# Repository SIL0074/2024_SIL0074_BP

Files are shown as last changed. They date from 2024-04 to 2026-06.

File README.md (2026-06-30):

# Přehrávač internetového rádia využívající technologii WiFi 🇨🇿 🇸🇰

Tento repozitář obsahuje zdrojové kódy k bakalářské práci, která se zabývá návrhem a konstrukcí zařízení pro přehrávání internetových rádií pomocí modulu ESP32 s integrovanou WiFi technologií.

Práce zahrnuje teoretickou část, která se věnuje stručně WiFi a Bluetooth, mikrokontroléru ESP32, zvukovému modulu VS1053B, LCD displeji, IR ovladači a pulznímu enkodéru. Důkladně popisuje rozložení pinů těchto modulů, jejich funkce a možné využití. Dále obsahuje rešerši komerčních WiFi rádií. Cílem práce je nejen navrhnout a sestrojit funkční zařízení, ale také detailně prozkoumat technické aspekty WiFi rádií a uživatelského rozhraní. Tento projekt má potenciál přispět k rozvoji oblasti internetových rádií a sloužit jako inspirace pro další inovace v této oblasti.

## Použitý hardware

- Mikrokontrolér ESP32 (Wi-Fi / Bluetooth SoC)
- Zvukový dekódovací modul VS1053B, LCD displej
- Infračervený (IR) ovladač a přijímač, rotační pulzní enkodér

## Autor

Bc. Pavel Šiller (2024)

**Usnesení:** Tento projekt byl vytvořen primárně pro účely vysokoškolské bakalářské práce. Zdrojové kódy a hardwarové návrhy jsou poskytovány „tak jak jsou“ bez záruky vhodnosti pro produkční využití nebo průmyslové nasazení. Autor nenese odpovědnost za případné škody způsobené jejich použitím. Uvedená řešení mohou sloužit jako vzdělávací demonstrace a inspirace pro vývoj IoT a audio systémů.

---

# Internet Radio Player Using WiFi Technology 🇬🇧 🇺🇸

This repository contains the source code for a bachelor’s thesis focused on the design and construction of a device for playing internet radios using the ESP32 module with integrated WiFi technology.

The work includes a theoretical part that addresses WiFi and Bluetooth technology, the ESP32 microcontroller, the VS1053B audio module, an LCD display, an IR controller, and a rotary encoder. It thoroughly describes the pinout of these modules, their functions, and potential applications. Furthermore, it includes a review of commercial WiFi radios. The aim of the thesis is not only to design and build a functional device but also to extensively explore the technical aspects of WiFi radios, and user interface. This project has the potential to contribute to the development of internet radios and serve as inspiration for further innovations in this field.

## Used hardware

- ESP32 Microcontroller (Wi-Fi / Bluetooth SoC)
- VS1053B Audio Decoder Module, LCD Display Module
- Infrared (IR) remote controller & receiver, rotary pulse encoder

## Author

Bc. Pavel Siller (2024)

**Disclaimer:** This project was created primarily for the purposes of a university bachelor’s thesis. Source codes and hardware designs are provided "as is" without warranty of fitness for production use or industrial deployment. The author takes no responsibility for any damages caused by their use. The provided solutions serve as educational demonstrations and inspiration for developing IoT and audio systems.

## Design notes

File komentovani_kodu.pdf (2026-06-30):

## Komentované cásti kódu ˇ

//Načtení všech potřebných knihoven

#include <WiFi.h>

#include <ESPAsyncWebServer.h>

#include <ArduinoOTA.h>

#include <HTTPClient.h>

#include <cbuf.h>

#include <SPI.h>

#include <Arduino.h>

#include <Preferences.h>

#include <web_content.h>

#include <LiquidCrystal_I2C.h>

#include <IRremoteESP8266.h>

#include <IRrecv.h>

#include <BluetoothA2DPSink.h>

#include <Adafruit_VS1053.h>

#include <VS1053.h>

#include <RotaryEncoder.h>

Prvne je pot ˇ | ˇreba nacíst veškeré knihovny pot ˇ | ˇrebné pro funkci rádia. Pˇridány jsou
knihovny Wifi.h, HTTPClient.h pro správnou funkci spojení se streamovacím serverem. Pro funkci vytvoˇrení webového serveru pˇrímo v ESP jsem použil knihovny ESPAsyncWeb-Server.h a mnou vytvoˇrenou knihovnu web_content.h pro definování struktury HTML kódu. Dále jsou zde knihovny jako ArduinoOTA.h pro funkci OTA nebo Preferences.h pro možnost ukládání promenných natrvalo do NVS (Non-Volatile Storage), která je náhražkou ˇ pameti EEPROM (Electric Erasable Programable Read Only Memory) u Arduina. ˇ Knihovny používané pro Bluetooth, jako jsou BluetoothA2DPSink.h a cbuf.h. Knihovny SPI.h, VS1053.h a Adafruit_VS1053.h pro zvukovou kartu a knihovny pro periferie a ovládací prvky IRemoteESP8266.h, IRrecv.h, RotaryEncoder.h a LiquidCrystal_I2C.

//Definování pinů

//Zvuková karta VS1053b

#define VS1053_CS 5

#define VS1053_DCS 16

#define VS1053_DREQ 4

#define VS1053_CSSD 17

#define CLK 18

#define MISO 19

#define MOSI 23

//Infračervený přijímač (OUT)

#define IR_REC 2

//Tlačítko pro přepínání mezi WiFi a Bluetooth režimy

#define BT_PIN 33

//Rotační enkódér

#define BUTTON_PIN 12

#define DT_PIN 13

#define CLK_PIN 14

//Název zařízení v Bluetooth režimu

#define BT_NAME "ESP32 RADIO"

//Velikost bufferu (vyrovnávací paměti) pro knihovnu Adafruit_VS1053.h

- režim Bluetooth

#define BUFFSIZE 32

Další úryvek kódu definuje pˇriˇrazení pin˚u jednotlivým promenným. ˇ
V pˇríloze práce v souboru main.cpp je vyzobrazena inicializace knihoven i vytvoˇrení
potˇrebných promenných na ˇ | ˇrádcích 48 - 194.

//Funkce pro spouštění serveru v případě, že se ESP32 nedokázalo př

ipojit k žádné WiFi
void serverRun() {

WiFi.softAP(server_ssid, server_heslo);

server.on("/", HTTP_GET, [](AsyncWebServerRequest *request){

request->send(200, "text/html", obsahWeb); //Vytvoří se server

na IP zobrazené na displeji, kde se zobrazí html kód z prom

ěnné obsahWeb, která je uložená ve flash spolu s programem });

server.on("/", HTTP_POST, [](AsyncWebServerRequest *request){

if(request->hasParam("ssid", true) && request->hasParam("

password", true)) {

AsyncWebParameter* ssidParam = request->getParam("ssid",

true);

AsyncWebParameter* passwordParam = request->getParam("

password", true);

String newSSID = ssidParam->value();

String newPassword = passwordParam->value();

//Ukládání zadaného SSID a hesla do sharedPrefs

inicializované při spuštění ESP preferences.begin("wifi", false);

preferences.putString("ssid", newSSID);

preferences.putString("password", newPassword);

preferences.end();

delay(1000);

ESP.restart();

} else {

request->send(400, "text/plain", "Chybí potřebné parametry" );
}
});

server.begin();

//Serial.println("Server běží!");
}

Funkce pro vytvoˇrení webového serveru na ESP32. Webový serveru bude mít strukturu souboru web_content.h, kterou si m˚užete zobrazit v pˇríloze práce.

if (server_vych_mod == RADIO){

serverRun();

Serial.println("Přepínám na režim SERVER");

server_vych_mod = SERVER;
}

else {

serverRun();
}
}

else if (WiFi.isConnected()){

Serial.println("Spojení s WiFi úspěšně navázáno");
}
Spouští se pˇri neúspešném p ˇ | ˇripojení pomocí zadaných parametr˚u SSID a hesla k WiFi. Pˇri
tomto je tˇreba se pˇripojit na ESP32 pomocí WiFi a zadat do webového prohlížece IP adresu ˇ zobrazenou na LCD. Poté potvrdit odeslání nového SSID a hesla.

//Funkce volána při přepnutí z WiFi režimu do Bluetooth režimu

void startBluetooth(){

Serial.println("Přepínám na BT režim");

if (rad_vych_mod != BT_REZIM){

lcd.clear();

lcd.setCursor(0, 0);

lcd.print("BLUETOOTH");

lcd.setCursor(0,1);

lcd.print("Nastavovani..."); //Vypsání BLUETOOTH na displej }

stream_prehravac.stopSong(); //Pozastavení inicializované knihovny

VS1053.h
stream_prehravac.softReset();

delay(1000);

if (!bt_prehravac.begin()) {

Serial.println(F("Chyba VS1053b, zkontroluj zapojení pinů!"));

lcd.clear();

lcd.setCursor(0,0);

lcd.print("Chyba E1");

while(1);

}

bt_prehravac.begin(); //Start zvukové karty pomocí knihovny

Adafruit_VS1053.h

ArduinoOTA.end(); //Vypnutí OTA

WiFi.mode(WIFI_OFF); //Vypnutí WiFi

WiFi.disconnect();

Serial.println("WiFi režim: " + WiFi.getMode()); //Testovací výpis

pro kontrolu
delay(1000);

circBuffer.flush(); //Vyprázdnění vyrovnávací paměti

Serial.println(stream_prehravac.isChipConnected()); //Testovací vý

pis pro kontrolu
a2dp_sink.set_stream_reader(dat_stream, false); //Nastavení

Bluetooth streamu
a2dp_sink.set_avrc_metadata_callback(metadata); //Nastavení metadat
- nepoužívám jej pro výpis jinde, než v konzoli, není třeba a2dp_sink.start(BT_NAME); //Start Bluetooth se jménem v BT_NAME

Serial.println(a2dp_sink.get_connected_source_name()); //Testovací v

ýpis pro kontrolu
delay(1000);

circBuffer.write((char *)bt_wav_header, 44);

delay(1000);

Serial.println("Bluetooth režim"); //Testovací výpis pro kontrolu

if (rad_vych_mod != BT_REZIM){ //Výpis informace o režimu na LCD

displej spolu s názvem BT
lcd.clear();

lcd.setCursor(0, 0);

lcd.print("BLUETOOTH");

lcd.setCursor(0,1);

lcd.print(BT_NAME);
}

rad_vych_mod = BT_REZIM; //Přepnutí režimu na BT_REZIM }

Pomocí funkce výše se pak zapíná Bluetooth režim (respektive se vypíná WiFi a zapíná Bluetooth), kdy je tˇreba vypnout WiFi z d˚uvodu interference ve stejném kmitoctovém pásmu. ˇ Poté je tˇreba vypnout inicializovanou zvukovou kartu knihovny VS1053.h a inicializovat zvukovou kartu knihovny Adafruit_VS1053.h.

//Tato funkce je volána při přepínání z Bluetooth do rádiového režimu

void stopBluetooth(){

lcd.clear(); //Výpis toho, co se s rádiem děje

lcd.setCursor(0, 0);

lcd.print("BLUETOOTH");

lcd.setCursor(0,1);

lcd.print("Vypinani...");

a2dp_sink.end();

delay(500);

Serial.println("Přepínám na WiFi režim");

bt_prehravac.stopPlaying();

bt_prehravac.reset();

ESP.restart();

Funkce pro vypnutí Bluetooth a pˇrepnutí do WiFi režimu. Kv˚uli nemožnosti správneˇ vypnout WiFi v ESP jsem nucen restartovat rádio a pˇrepojit do WiFi režimu až po startu.

void Enkoder() {

static int poz = 1;
int novaPoz = enkoder->getPosition(); //Získání pozice

int smerST;

V této funkci enkóderu se nachází zvlášt’ switch pro pˇrepínání režim˚u WiFi/Bluetooth a v
každém z nich poté ješte switch mezi p ˇ | ˇrepínámím hlasitost/stanice.

case WIFI_REZIM:
if (poz != novaPoz) {

switch (enk_vych_mod) { //Volba režimu enkódéru

case enkoder_stanice: //Přepínání stanic

//Zjištění směru otáčení

smerST = (int)(enkoder->getDirection());

//Podmínky pro otáčení enkódérem

if (smerST > 0 && ID_stanice < pocet_stanic) {

ID_stanice++;
} else if (smerST < 0 && ID_stanice > 1) {

ID_stanice--;
}

Serial.print("pozST:"); //Vypisování do serialu (pro testování)

Serial.print(ID_stanice);

Serial.print("smerST:");

Serial.println(smerST);

poz = novaPoz; //Uložení pozice do poz

zaloha_stanice = ID_stanice; //Uložení ID stanice do

zaloha_stanice

break;
case enkoder_hlasitost: //Změna hlasitosti

int smerVO = (int)(enkoder->getDirection()); //smerVO nabývá

hodnot 1 a -1 dle knihovny RotaryEncoder.h
if (smerVO > 0 && Volume < 100) {//Pokud je 1, zvýšení

hlasitosti o 1

Volume++;
} else if (smerVO < 0 && Volume > 29) {//Pokud je -1, snížení

hlasitosti o 1

Volume--;
}

Serial.print("pozVO: ");//Vypisování do serialu (pro testování)

Serial.print(enkoderPozVO);

Serial.print("smerVO: ");

Serial.println(smerVO);

Serial.print("Volume: ");

Serial.print(Volume);

poz = novaPoz;//Zápis nové polohy

break;
}
}

break;

Zde je zase videt, jakým zp˚usobem se chovají p ˇ | ˇrepnuté case ve WiFi režimu. Vše je na
základe sm ˇ | eru otá ˇ | cení enkóderu. Samoz ˇ | ˇrejme nechybí ošet ˇ | ˇrení hranicních interval˚u hlasitosti. ˇ

case BT_REZIM:

if (poz != novaPoz) {

switch (enk_vych_mod) {

case enkoder_stanice: //Využil jsem již existující

enkoder_stanice (přepíná skladby v playlistu připojeného zaří

zení)

//Zjištění směru otáčení smerST = (int)(enkoder->getDirection());

if (smerST > 0) {

a2dp_sink.next(); //Přepnutí vpřed

} else if (smerST < 0) {

a2dp_sink.previous();//Přepnutí vzad
}

Serial.print("posST:");//Vypisování do serialu (pro testování)

Serial.print(" dirST:");

Serial.println(smerST);

Serial.print(bluetooth_media_title);

poz = novaPoz;//Zápis nové polohy

break;

case enkoder_hlasitost://Jako u WiFi režimu je zde změna

hlasitosti
//Zjištění směru otáčení

int smerVO = (int)(enkoder->getDirection());

//Podmínky pro otáčení enkódérem

if (smerVO > 0 && VolumeBT > 1) {

VolumeBT--;
} else if (smerVO < 0 && VolumeBT < 101) {

VolumeBT++;
}

Serial.print("posVO:");//Vypisování do serialu (pro testování)

Serial.print(enkoderPozVO);

Serial.print(" dirVO:");

Serial.println(smerVO);

Serial.print(" VolumeBT:");

Serial.print(VolumeBT);

poz = novaPoz;//Zápis nové polohy

break;
}
}

break;
}

Opet p ˇ ˇrepínání hlasitost/stanice v Bluetooth režimu.

//Funkce pro tlačítko, které přepíná režimy enkódéru

void handleButton() {

if (digitalRead(BUTTON_PIN) == LOW) {

if (!buttonPressed) {

buttonPressed = true;

//přepnutí stavu

if (enk_vych_mod == enkoder_stanice) {

enk_vych_mod = enkoder_hlasitost; Serial.println("Měním hlasitost!");

} else {

enk_vych_mod = enkoder_stanice; Serial.println("Přepínám stanice!"); }
}

} else {

buttonPressed = false;
}
}
Funkce sloužící pro podchycení funkcnosti tla ˇ | cítka na enkóderu. ˇ
Mení stavy p ˇ | ˇrepnutí hlasitost/stanice v promenné ˇ | enk_vych_mod.

void IROvladac() {

if (irrecv.decode(&decod_prij)) {

Serial.println(decod_prij.value, HEX);

V tomto úryvku nalezneme funkci IR diody. Pˇríchozí signál je tˇreba dekódovat a následneˇ na základe p ˇ ˇrijatého hexadecimálního kódu (HEX) urcit proces, který se má vykonat. ˇ switch (rad_vych_mod){ //Pro WiFi a Bluetooth rozlišné funkce

case WIFI_REZIM:

if (decod_prij.value == 0xFFB04F) { // tlačítko "#"

Serial.println("Restart za 2s!");

delay(1500);

ESP.restart();
}

Jak jsem zmínil výše, je tˇreba pˇriˇradit hexadecimálnímu kódu jeho úlohu. Zde je pˇríklad
HEX kódu 0xFFB04F pˇriˇrazeno pro restart ESP (jedná se o tlacítko se symbolem ˇ | #). Tyto
stejné úlohy lze pˇriˇrazovat v Bluetooth režimu zvlášt’.

String Scroll_displeje(String LCD_text){

String LCD_hot;

String LCD_proces = odsazeni + LCD_text + odsazeni; LCD_hot = LCD_proces.substring(x1,x2);

x1++;

x2++;
if (x1>LCD_proces.length()){

x1=16;

x2=0;
}

return LCD_hot;
}

Zde vidíme funkci pro možnost pohyblivého displeje (respektive jeho prvního ˇrádku) z d˚uvodu délky názvu stanic, zeme p˚uvodu stanice a identifikátoru stanice. Kód je inspirován ˇ kódem ze stránky s názvem I2C LCD interfacing with Arduino Display Scrolling Text and Custom Characters. (https://microcontrollerslab.com/i2c-lcd-arduino-tutorial/) [?]

//Funkce pro tlačítko, které přepíná mezi režimy WiFi a BT

void BTbutton() {

//Ošetření nechtěného přepínání

BTbuttonState = digitalRead(BT_PIN);

unsigned long currentTime = millis();

if (BTbuttonState == LOW) {

if (currentTime - BTlastButtonPressTime >= BTdebounceDelay) {

delay(50);

if (rad_vych_mod == WIFI_REZIM) {

//Zapnutí Bluetooth, pokud jsme ve WiFi režimu

startBluetooth();

Serial.println("Přepínám do BT režimu");

delay(1000);

Serial.println("Přepnuto!");

} else if (rad_vych_mod == BT_REZIM) {

//Zastavení Bluetooth, pokud jsme v Bluetooth režimu

stopBluetooth();

Serial.println("Přepínám do WiFi režimu");

delay(1000);

Serial.println("Přepnuto!");
}

BTlastButtonPressTime = currentTime; }
}
}
Tlacítko pro p ˇ | ˇrepínání režim˚u WiFi/Bluetooth. Je zde nastavena ochrana proti nechtenému ˇ
delšímu držení tlacítka. ˇ

//Funkce pro samotný stream

void stream(){

if(!webclient.connected() || pamet_ID_stanice!=ID_stanice){

if(webclient.connect(host, 80)){ | //Př

ipojení se k požadovanému streamu webclient.print(String("GET ") + cesta+ " HTTP/1.1\r\n" + "Host:

" + host + "\r\n" + "Connection: close\r\n\r\n");

pamet_ID_stanice=ID_stanice;
Serial.println(nazev); //Vypsání názvu do serialu, pro testovací

účely
lcd.clear(); //čistka displeje
}

else {

Serial.println("Nepodařilo se připojit k serveru.");

lcd.clear();

lcd.setCursor(0,0);

lcd.println("Chyba E2");

stream_prehravac.stopSong(); }
}

if(webclient.available() > 0){

uint8_t bytesread = webclient.read(mp3buff,32); | //naplnění

bufferu při dostupnosti serveru
stream_prehravac.playChunk(mp3buff,bytesread); | //přehrávání

audio streamu z bufferu na výstup VS1053
}
}
Zde je proces samotného žádání streamu po streamovacím serveru. V pˇrípade úsp ˇ | ešného ˇ
pˇripojení se naplní vyrovnávací pamet’ (buffer) a p ˇ | ˇrehraje audio obsah.

//Naplnění bufferu

void dat_stream(const uint8_t *data, uint32_t length) {

if (circBuffer.room() > length) {

if (length > 0) {

circBuffer.write((char *)data, length); }

} else {
Serial.println("\nŽádná streamovací data!"); }
}
Naplnení dat do ˇ | circBuffer.

//Průběh Bluetooth streamu, volá se ve smyčce

void handle_stream() {

if (circBuffer.available()) {

if (bt_prehravac.readyForData()) { //Dotaz na zvukovou kartu, zda

může přijímat další data

int bytesRead = circBuffer.read((char *)mp3buff, BUFFSIZE);

//Zachycení chybného čtení dat

if (bytesRead != BUFFSIZE) Serial.printf("Málo dat v bufferu,

kvalita audia může být ovlivněna", bytesRead);

bt_prehravac.playData(mp3buff, bytesRead); //Zaslání dat do

zvukové karty
}
}
}
Hlavní funkce pro beh bluetooth spojení. Data z ˇ | circBuffer se pouští na zvukové desce.

void setup ()
{

Serial.begin(115200);

delay(500);

SPI.begin(); //Inicializace SPI

if (!bt_prehravac.begin()) {

Serial.println(F("Nedetekováno žádné VS1053B, zkontroluj zapojení

pinů! Zařízení nebude fungovat!"));

while(1);
}

stream_prehravac.begin(); // Start zvukové karty VS1053B pomocí

knihovny VS1053.h

pinMode(BUTTON_PIN, INPUT_PULLUP); //Nastavení GPIO pinů jako vstup (

tlačítko na enkódéru a Bluetooth tlačítko)

pinMode(BT_PIN, INPUT_PULLUP);

Serial.println("Enkódér úspěšně inicializován!");

enkoder = new RotaryEncoder(DT_PIN, CLK_PIN, RotaryEncoder::LatchMode

::TWO03);//Inicializace rotačního enkódéru

irrecv.enableIRIn(); //Inicializace IR diody

attachInterrupt(digitalPinToInterrupt(DT_PIN), getPoz, CHANGE); //

Nastavení přerušení při změně na DT_PIN nebo CLK_PIN attachInterrupt(digitalPinToInterrupt(CLK_PIN), getPoz, CHANGE);

lcd.init(); // Inicializace LCD displeje

lcd.backlight();

lcd.clear();

lcd.setCursor(0,0);

lcd.print("Radio - SIL0074");

lcd.setCursor(0,1);

lcd.print("Start radia");

Serial.println("Startuji");

WiFi.mode(WIFI_STA); //Nastavení režimu WiFi (STA - station mode)

delay(1000);

// WiFi.begin(ssid, pass);

//serverRun();

WiFi.begin(ssid, pass); //Připojení pomocí SSID a hesla

Úryvek kódu je z funkce setup(), kde se provede nastavení režim˚u pin˚u, režimy enkóderu,

aktivace displeje nebo se nastaví režim WiFi na STA (Station mode). Je zde taktéž pokus o prvotní pˇripojení na WiFi s parametry SSID a heslem.

if (!WiFi.isConnected()) { //Jestliže se nepodaří ani to, informuje

se uživatele o chybě spojení na serial
Serial.println("Chyba připojení!");

//Spuštění serveru a přepnutí do režimu SERVER

if (server_vych_mod == RADIO){

serverRun();

Serial.println("Přepínám na režim SERVER");

server_vych_mod = SERVER;
}

else {

serverRun();
}
}

else if (WiFi.isConnected()){

Serial.println("Spojení s WiFi úspěšně navázáno"); }

Podmínka pro úspešné ˇ | ci neúsp ˇ | ešné p ˇ | ˇripojení.
V pˇrípade úsp ˇ | ešného spojení p ˇ | ˇrejde rádio volne setup funkcí bez zm ˇ | eny režimu. Jestliže ˇ
se však nepodaˇrí pˇripojit, spustí se server režim, ve kterém lze manuálne nastavit SSID a ˇ heslo.

//Zprovoznění OTA

ArduinoOTA.setHostname("ESP32");

//ArduinoOTA.setPassword("SIL0074"); //možnost nastavení hesla

ArduinoOTA.begin();

Spuštení OTA, je zde možnost nastavit heslo, tuto možnost jsem nevyužil. ˇ

preferences.begin("radio", true); //Získání hodnot z sharedPrefs

Volume = preferences.getInt("Volume", Volume);

VolumeBT = preferences.getInt("VolumeBT", VolumeBT);

ID_stanice = preferences.getInt("ID_stanice", ID_stanice);

preferences.end();

Nactení dat z ˇ | preferences, do kterých se ukládá aktuální hodnota hlasitosti z obou režim˚u a
identifikátor stanice. Jsou tak zachované i po restartu rádia.

//Hlavní smyčka programu

void loop()
{

switch(server_vych_mod){//Přepínání mezi RADIO a SERVER režimem

case RADIO:

Ukázka hlavní smycky, kde se pomocí switche ˇ | server_vych_mod najede do pˇríslušného
režimu radio/server.

switch(rad_vych_mod)//Přepínání mezi WiFi a Bluetooth režimem

{

case WIFI_REZIM:

V režimu radio se poté pˇrepíná mezi režimy WiFi/Bluetooth.

//V případě server režimu

case SERVER:

if (!IPdone) {

lcd.clear();

lcd.setCursor(0, 0);

lcd.print("Server rezim");//Výpis na LCD displej

lcd.setCursor(0, 1);

lcd.print("IP: ");//Výpis na LCD displej

String serverIP = WiFi.softAPIP().toString();

lcd.print(serverIP);//Výpis IP serveru na LCD displej

Serial.println("IP VYPSANA");

IPdone = true;
}

Prikazy(); //Detekce příkazů v server režimu

break;

V režimu server se už nepˇrepíná a pouze se vypíše na LCD displej potˇrebný text pro informaci uživatele.

case WIFI_REZIM:

if (Obnova >= 450){//Po kolika cyklech se má obnovit LCD

Obnova = 0; //Reset

String nazevCely = nazev + "|" + nar + "|" + ID_stanice;

lcd.setCursor(0, 0);

String pohybText = Scroll_displeje(nazevCely);

lcd.print(pohybText); //vypsání infa o stanici na první řádek LCD

Zde se celý režim odehrává pod podmínkou pocítadla ˇ Obnova, urcuje, po kolika opakováních ˇ se vykoná aktualizace hlasitosti a LCD displeje. Hodnota 450 je ideální pro plynulou obnovu a minimalizaci efektu ghosting na displeji.
Dále se zde volá funkce pro pohyblivý název stanice, zemi p˚uvodu stanice a identifikátor stanice.

if (Volume != predVolume) {

lcd.setCursor(0, 1);

lcd.print(" | "); //Smazání druhého řádku LCD

displeje
lcd.setCursor(0, 1);

if (Volume < 30){

lcd.print("Zvuk vypnut");//vypsání na druhý řádek LCD }

else{

lcd.print("Hlasitost: ");//vypsání na druhý řádek LCD

lcd.print(mapVolume);

lcd.print ("%");
}

//aktualizace hlasitosti

predVolume = Volume;
}

else{

lcd.setCursor(0, 1);

if (Volume < 30){

lcd.print("Zvuk vypnut"); //vypsání na druhý řádek LCD }

else{

lcd.print("Hlasitost: ");//vypsání na druhý řádek LCD

lcd.print(mapVolume);

lcd.print ("%");
}
}

preferences.begin("radio", false); //ukládání do prefs

preferences.putInt("Volume", Volume);

preferences.putInt("ID_stanice", ID_stanice);

preferences.end();
}
Funkcnost a aktualizace hlasitosti ve smy ˇ | cce pouze však ve chvíli, kdy se hlasitost zm ˇ | enila ˇ
(aktualizace neprobehne, jestliže je hlasitost na stejné úrovni). Uložení hodnot ˇ | | Volume a
ID_stanice do preferences.

switch(ID_stanice){ | // Přepínání stanic - ID stanice

case 1:

nazev = "Hitradio Orion";

host = "ice.abradio.cz";
cesta= "/orion128.mp3";

nar ="CZ";

break;

case 2:

nazev = "Evropa 2";

host= "ice.actve.net";
cesta= "/fm-evropa2-128";

nar ="CZ";

break;

Ukázka funkcnosti r˚uzných stanic, nachází se zde switch pro p ˇ | ˇrepínaní ID_stanice. Každá
stanice má pak vlastní case a parametry, které se nacítají a zobrazují na displej. ˇ
Já mám nastaveno 30 stanic, tudíž mám 30 case.

stream(); //funkce pro stream

IROvladac(); //aktualizace IR

Enkoder();//aktualizace enkódéru

handleButton(); //aktualizace tlačítka

Prikazy();//aktualizace příkázů

BTbutton();//aktualizace BT tlačítka

Opet volány všechny funkce zmín ˇ | ené výše. ˇ

//Funkce v BT režimu

case BT_REZIM:
//Pokud není BT spuštěno, zapni jej

if (!a2dp_sink.is_connected()){

startBluetooth();
}

//Refresh LCD v BT režimu

if (Obnova >= 20000){

Obnova=0;
bt_prehravac.setVolume(VolumeBT, VolumeBT); //Nastavení hlasitosti

VS1053b

V bluetooth režimu se vyskytuje pocítadlo ˇ | Obnova taktéž, je nastaveno na rozdílnou hodnotu,
protože je bluetooth na výkon o dost nárocnˇ ejší a p ˇ | ˇri cast ˇ | ejších obnovách mohou nastat ˇ
problémy. Taková vysoká hodnota pocítadla však nijak nezhoršuje zážitek z rádia. ˇ
Taktéž se nastavuje hlasitost na zvukovou desku (v této knihovne žáleží na levém a ˇ pravém kanálu, tudíž je tˇreba vyplnit dve pozice). ˇ

//Mapování hodnot hlasitosti v jiném pořadí a v jiném intervalu

int mapVolumeBT = map(VolumeBT, 1, 100, 100, 1);

if (mapVolumeBT == 0 || VolumeBT == 254){

lcd.clear();

lcd.setCursor(0, 0);

lcd.print("BLUETOOTH");//Výpis na LCD displej

lcd.setCursor(0,1);

lcd.print("Zvuk vypnut"); //Výpis na LCD displej
}
Úryvek kódu ukazuje mapování hodnot v opacném po ˇ | ˇradí, knihovna totiž pracuje s opac-ˇ

nými hodnotami a chceme, abychom na LCD displeji videli, že 100% je opravdu hlasitost ˇ maximální, nikoliv minimální.
Pokud je zvuk vypnut, na displej se vypíše pˇríslušný text.

preferences.begin("radio", false); // Uložení hodnot do shared prefs

preferences.putInt("VolumeBT", VolumeBT);

preferences.end();

Uložení hodnoty hlasitosti v bluetooth režimu VolumeBT do preferences.

handle_stream(); //aktualizace streamu

IROvladac(); //aktualizace IR

Enkoder();//aktualizace enkódéru

handleButton(); //aktualizace tlačítka

Prikazy();//aktualizace příkázů

BTbutton();//aktualizace BT tlačítka

Obnova++;

Volání potˇrebných funkcí a inkrementace promenné ˇ Obnova.

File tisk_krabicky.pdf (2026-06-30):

Príprava krabi ˇ | cky pro 3D tisk ˇ
Vybereme objekt levým tlacítkem myši a v pravém horním rohu klikneme na tla ˇ | cítko ˇ
„Export“.

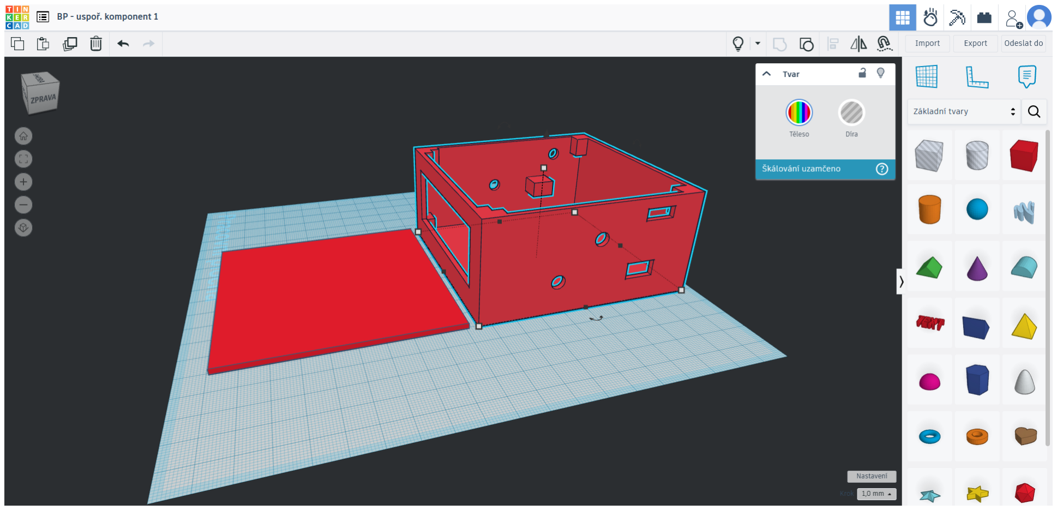
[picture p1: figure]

Obrázek 1: Export modelu z TinkerCAD prostˇredí do .stl formátu - oznacení objektu ˇ

Poté vybereme možnost „.STL“ a soubor si uložíme kdekoliv na úložišti.

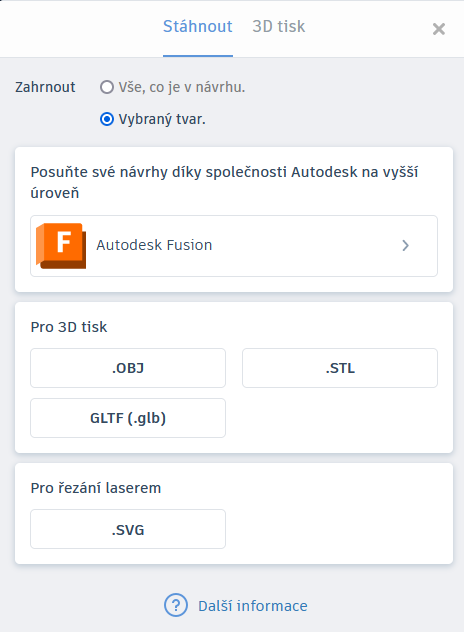
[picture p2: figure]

Obrázek 2: Export modelu z TinkerCAD prostˇredí do .stl formátu - export

Stejný postup aplikujeme pro víko, budeme mít tedy dva .stl objekty.
K dalšímu kroku potˇrebujeme program, který nám pˇripraví model k tisku a zašle model tiskárne. Pro tento krok jsem použil program PrusaSlicer. (https://www.prusa3d.com/cs/stranka/prusaslicer_424/) V tomto programu si oba mo- ˇ
dely otevˇreme. Udeláme to nap ˇ | ˇr. tak, že .stl soubor pˇretáhneme na spouštecí .exe soubor ˇ
PrusaSlicer.

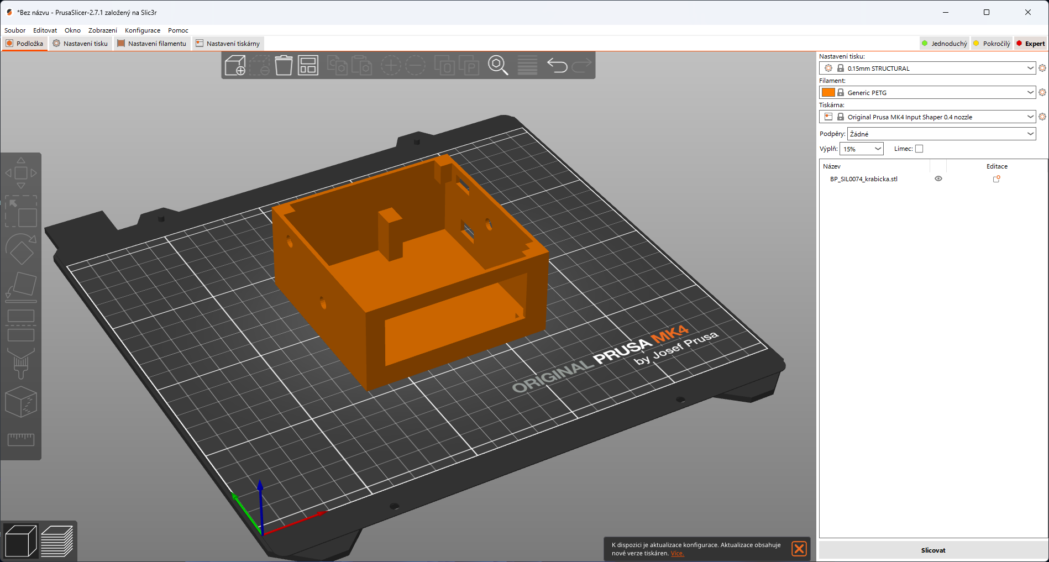
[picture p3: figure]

Obrázek 3: Otevˇrený program s importovaným modelem krabicky ˇ

Nyní musíme nastavit typy podper, pro krabi ˇ | cku se mi osv ˇ | edˇ cilo používat tzv. organické ˇ
podpery. Nastavíme je tak, že p ˇ | ˇrejdeme do sekce „Nastavení tisku“ v levém horním rohu a
poté do podsekce „Podpery“ ˇ | .

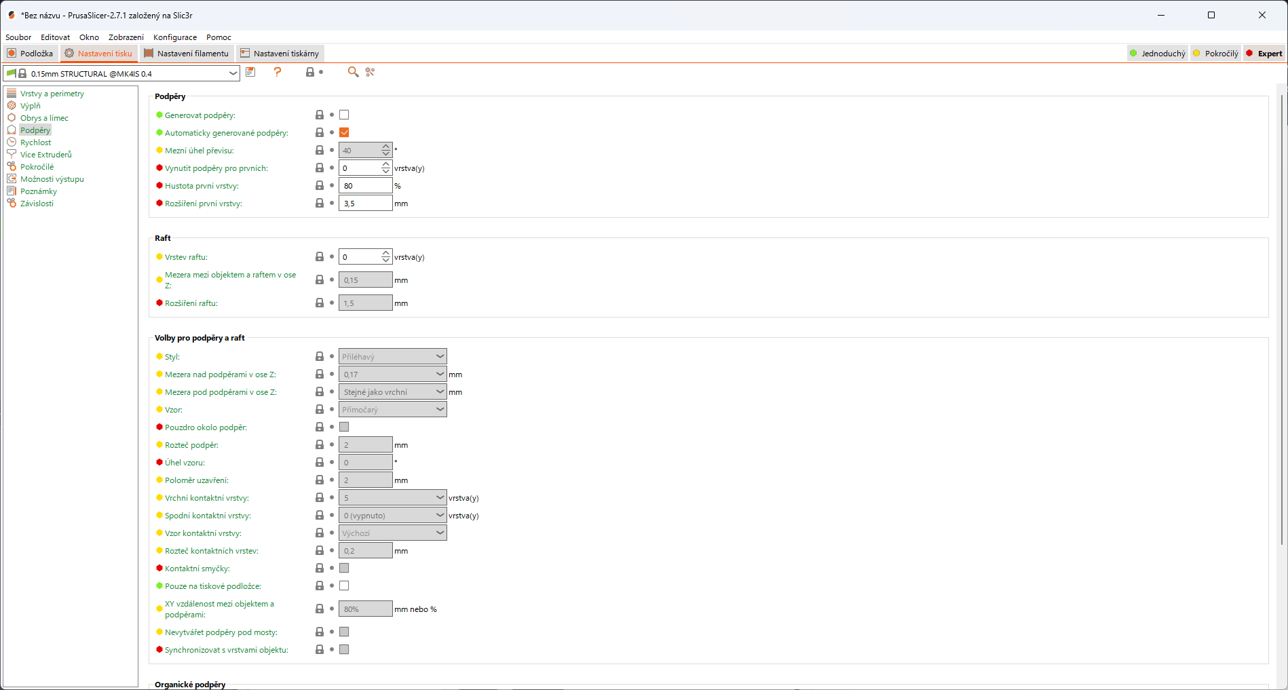
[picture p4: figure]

Obrázek 4: Menu pro nastavení podper v programu PrusaSlicer ˇ

Zde zapneme v oddílu „Podpery“ ˇ | funkci „Generovat podpery“ ˇ | , poté se nám odemkne
oddíl „Volby pro podpery a raft“ ˇ | , kde u funkce „Styl“ zvolíme „Organické“ pro volbu
organických podper. ˇ

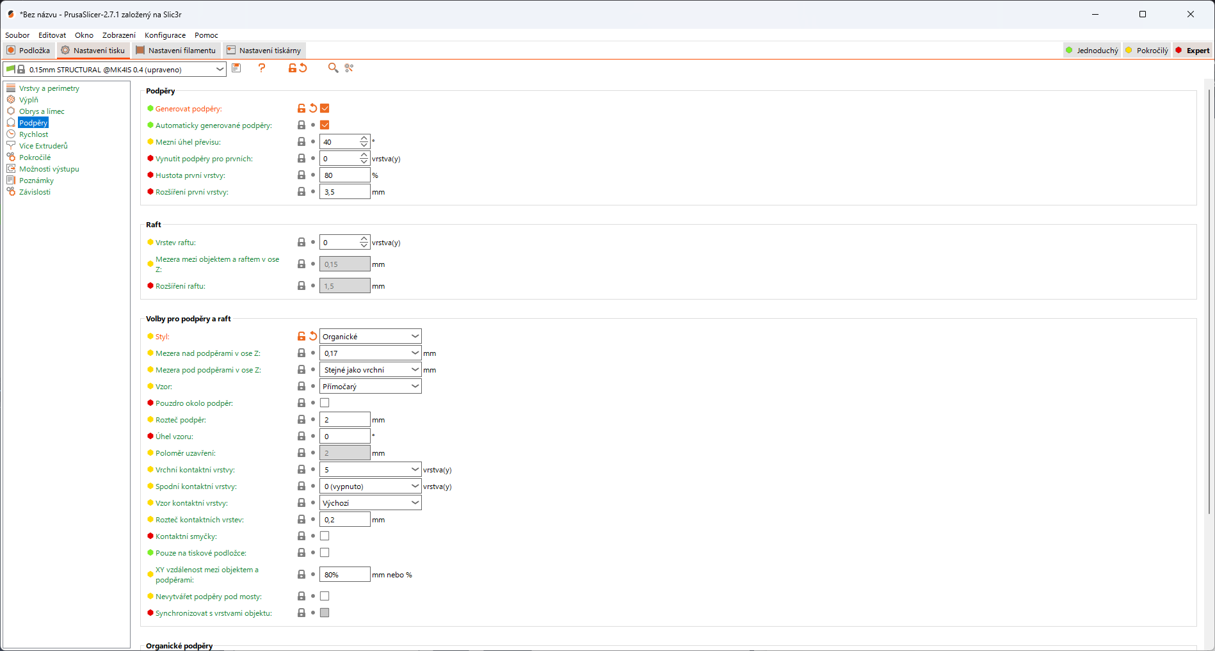
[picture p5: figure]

Obrázek 5: Nastavení stylu podper v programu PrusaSlicer ˇ

V dalším kroku se pˇrepneme zpet do sekce ˇ | „Podložka“, kde klikneme na tlacítko ˇ
„Slicovat“ pro pˇrípravu modelu pro tisk. Model se pˇripraví pro tisk a vygeneruje podpery. ˇ

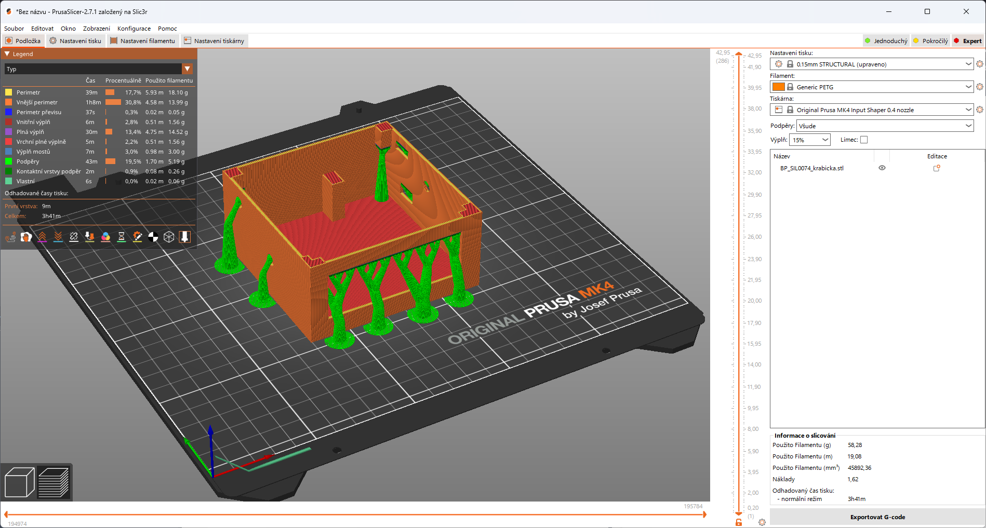
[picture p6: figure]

Obrázek 6: Model pˇripraven pro tisk v programu PrusaSlicer

Jako poslední úkon v tomto programu je kliknutí na tlacítko ˇ „Exportovat G-code“, exportovaný soubor poté nahrajeme na jakékoliv úložište a pomocí 3D tiskárny objekt ˇ vytiskneme.

Obrázek 7: Exportovaný soubor ve formátu .bgcode

Ty samé úkony provedeme s modelem víka, avšak u víka není tˇreba nastavovat podpery, ˇ protože žádné nejsou potˇreba, žádné jeho cásti nevisí ve vzduchu. ˇ
Jednotlivé 3D modely (krabicka, víko) najdete v p ˇ | ˇríloze této práce.

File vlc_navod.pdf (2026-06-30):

## Vytvorení vlastního streamu v domácí lokální síti ˇ

Pro vytvoˇrení vlastního streamu v domácí LAN (Local Area Network) lze využít širokou
škálu program˚u. Nejvetší zástupce t ˇ | echto p ˇ | ˇrehrávác˚u s možností vysílání streamu i sledování ˇ
streamu je VLC (VideoLAN Client), který je podporován ve Windows, Linuxu i macOS. Je napˇríklad možné vytvoˇrit z Raspberry Pi streamovací server, ke kterému se dá pˇripojit a sledovat video i poslouchat audio obsah. M˚užeme však použít i jiné pˇrehrávace, nap ˇ ˇr. KMPlayer (K-Multimedia Player) nebo PotPlayer. Já si pro ukázku vybral práve VLC, ˇ kterého postup popisuji níže. Je tedy potˇreba stáhnout a nainstalovat VLC. (https://www.videolan.org/vlc/download-windows.html) [?][?][?]

Stream audia pomocí VLC

Pˇri otevˇrení VLC vybereme položku Media -> Stream... nebo stiskneme klávesovou zkratku CTRL+S.

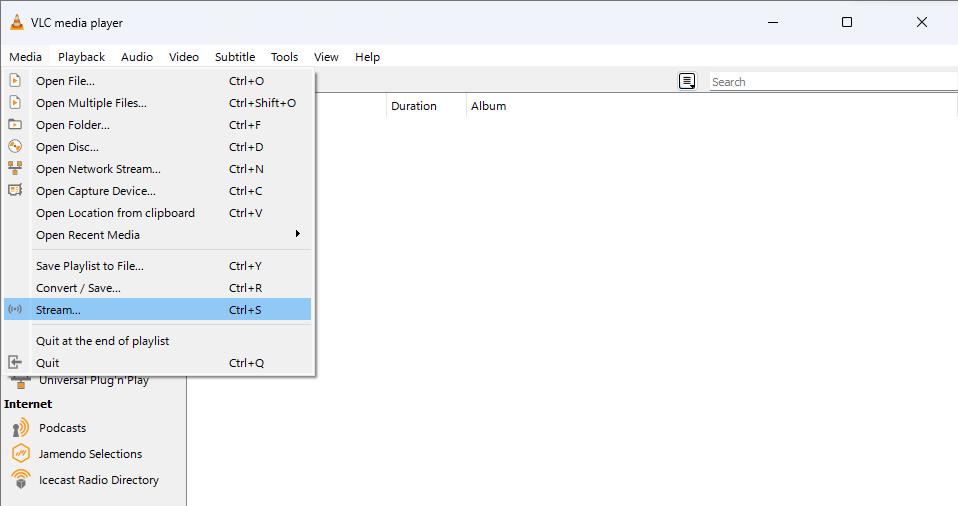
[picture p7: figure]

Obrázek 1: Položka „Media -> Stream...“

V otevˇreném okne Open Media vybereme položku ˇ | „Add...“, kde si zvolíme, který audio
soubor chceme streamovat. Pˇri zaškrtnuté volbeˇ „Show more options“ pak máme rozšíˇrené možnosti. Napˇríklad si m˚užeme zvolit soubor, který bude pˇrehráván po skoncení dále nebo ˇ pocet ms souboru, které se uloží do bufferu. ˇ
Jakmile máme vše nastaveno, klikneme na „Stream“.

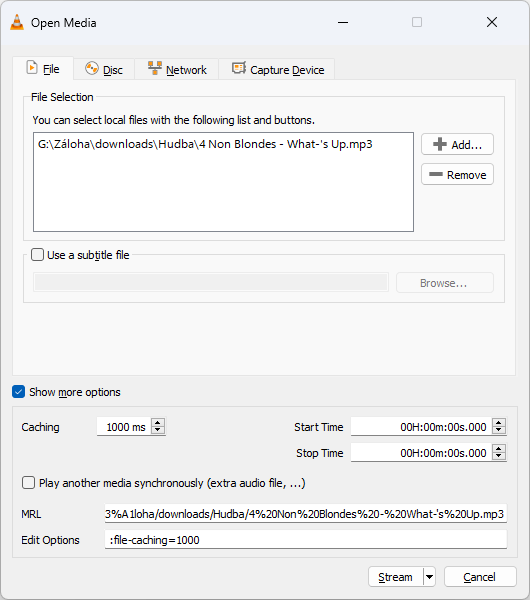
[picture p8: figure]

Obrázek 2: Položka „Add...“ s následne vybraným audio souborem ˇ

V dalším okne nám p ˇ ˇrehrávac shrne, kterou skladbu budeme streamovat. Klikneme volbu ˇ „Next“ pro pokrocení dále. ˇ

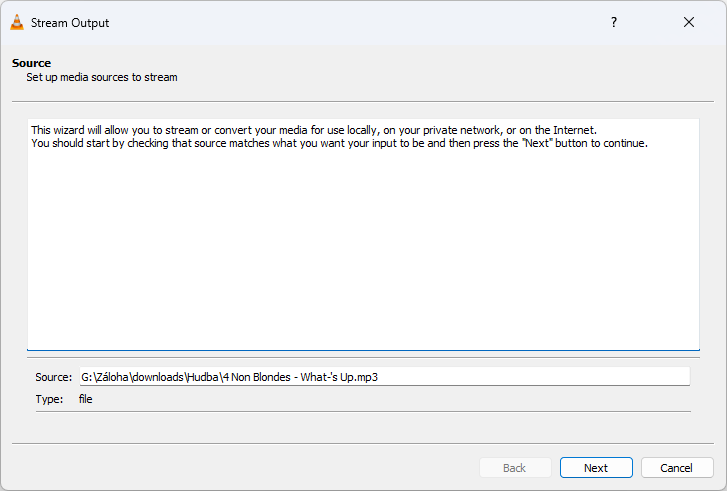
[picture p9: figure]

Obrázek 3: Shrnutí streamovaného souboru

V další cásti vybereme protokol, který chceme pro stream použít. V našem p ˇ | ˇrípadeˇ
zvolíme možnost HTTP protokol a klikneme na „Add“.

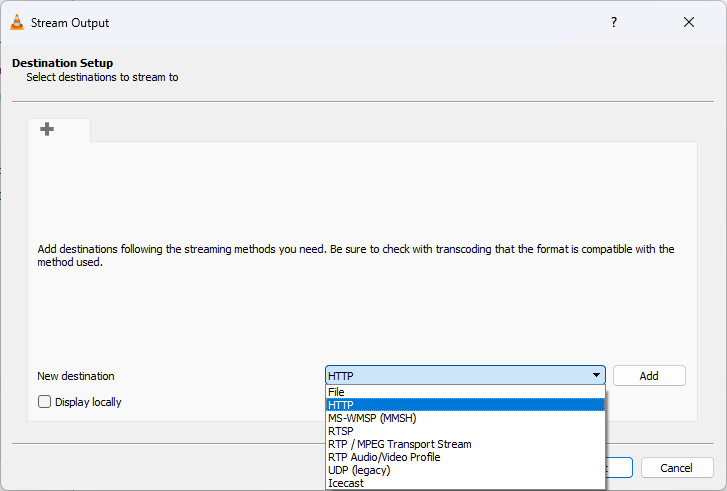
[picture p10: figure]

Obrázek 4: Výber protokolu pro streamování ˇ

Následne vybreme port 8080 (HTTP port). Výb ˇ | er umíst ˇ | ení m˚užeme nechat ve výchozím ˇ
stavu, a to je koˇren adresáˇre serveru. Následne klikneme na tla ˇ | cítko ˇ | „Next“.

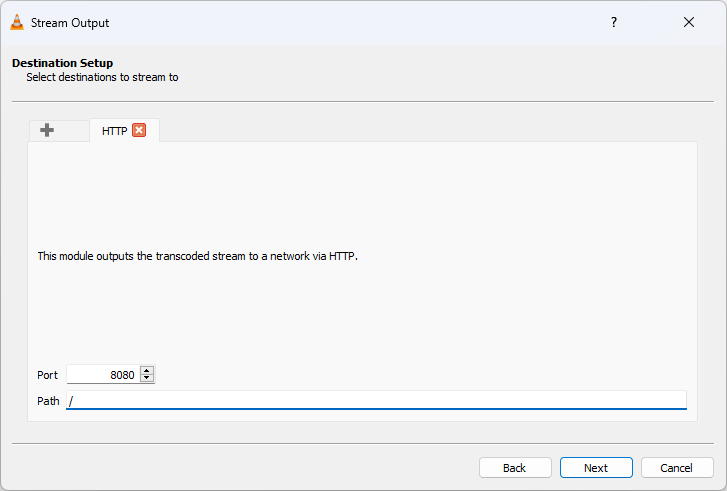
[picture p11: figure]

Obrázek 5: Vyber portu a umíst ˇ | ení streamu ˇ

Jako další volbu vybereme kódovací profil, pro audio jsem zvolil Audio-MP3. Pˇri kliknutí
na ikonku klíce m˚užeme upravit parametry profilu. Upravení bitratu, po ˇ | ctu kanál˚u nebo ˇ
vzorkovací frekvenci. Jestliže máme vybráno, m˚užeme kliknout na „Next“.

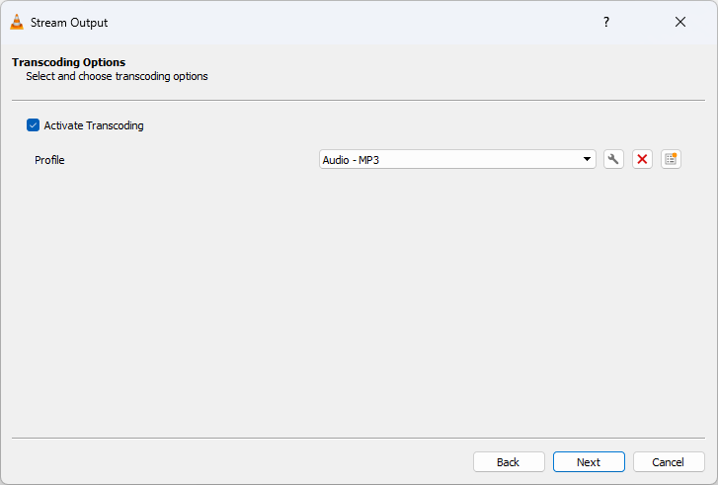
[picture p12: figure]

Obrázek 6: Vyber kódovacího profilu ˇ

V další cásti klikneme na ˇ | „Stream“ a VLC zacne daný soubor streamovat na p ˇ | ˇridelené ˇ
IP adrese sít’ové karty pocíta ˇ ce. ˇ

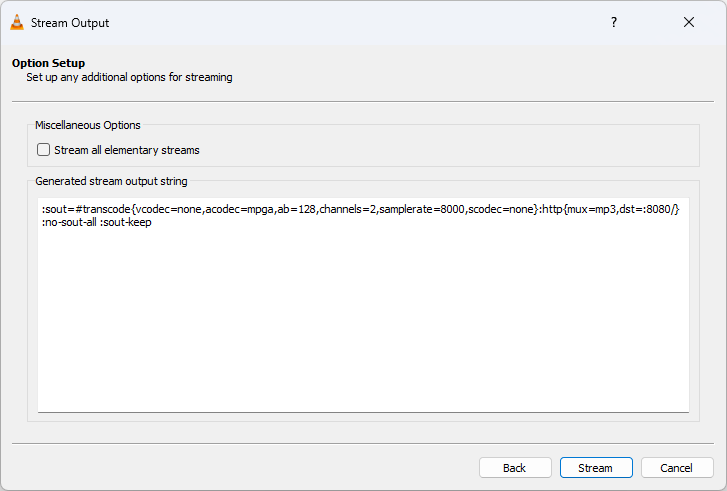
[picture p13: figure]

Obrázek 7: Kompletní shrnutí

Z pohledu klienta se pak v lokální síti m˚užeme pˇripojit na IP adresu zdrojové sít’ové karty. Tu m˚užeme zjistit ve Windows v CMD (Command Prompt) zadáním pˇríkazu ipconfig. V mém pˇrípade se jedná o IPv4 adresu 10.0.0.38. ˇ

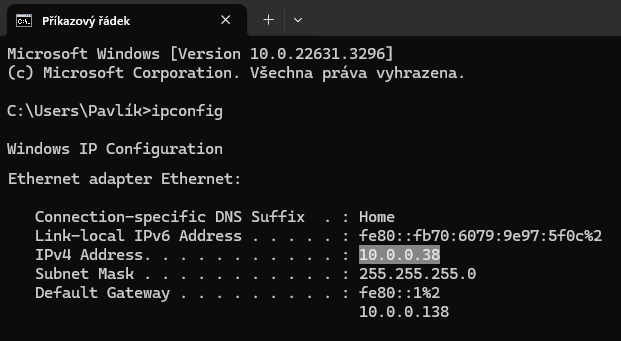
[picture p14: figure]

Obrázek 8: Pˇríkaz ipconfig a zjištení IP adresy ˇ

Z pohledu klienta pak vyberem ve VLC volbu „Open Network Stream...“ nebo stiskneme klávesovou zkratku CTRL+N.

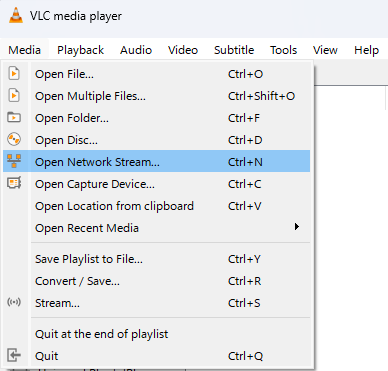
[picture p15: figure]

Obrázek 9: Výberˇ „Open Network Stream...“

Následne se zadáním IP adresy ve formátu ˇ | „http://IP-adresa:port“ pˇripojením na
stream. Konkrétne tedy http://10.0.0.38:8080 a stiskneme ˇ | „Play“.

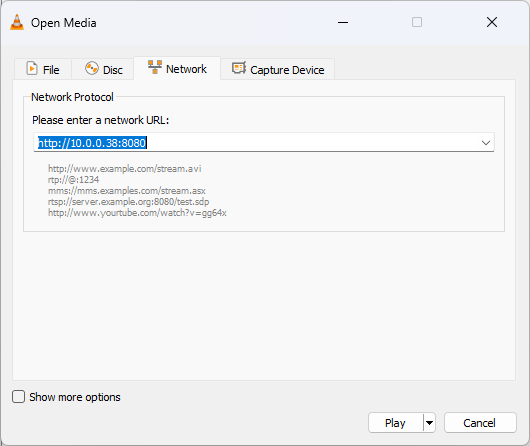
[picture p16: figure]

Obrázek 10: Zadání IP adresy hosta a pˇrehrání streamu

V levém okne jsem se p ˇ | ˇripojil pomocí IP adresy na streamovaný soubor v pravém okne.ˇ

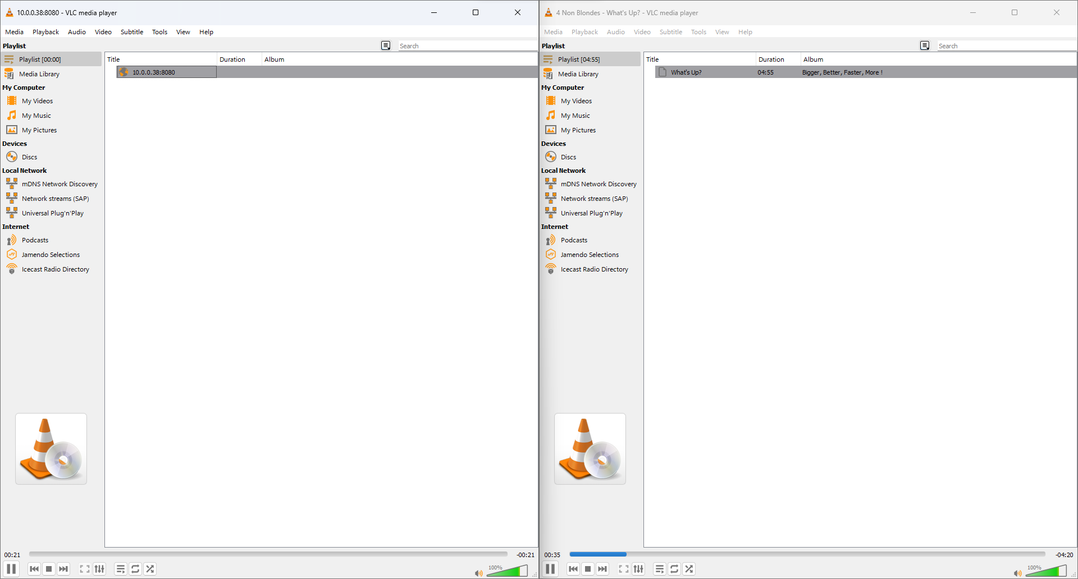
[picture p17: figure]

Obrázek 11: Streamovaný audio soubor

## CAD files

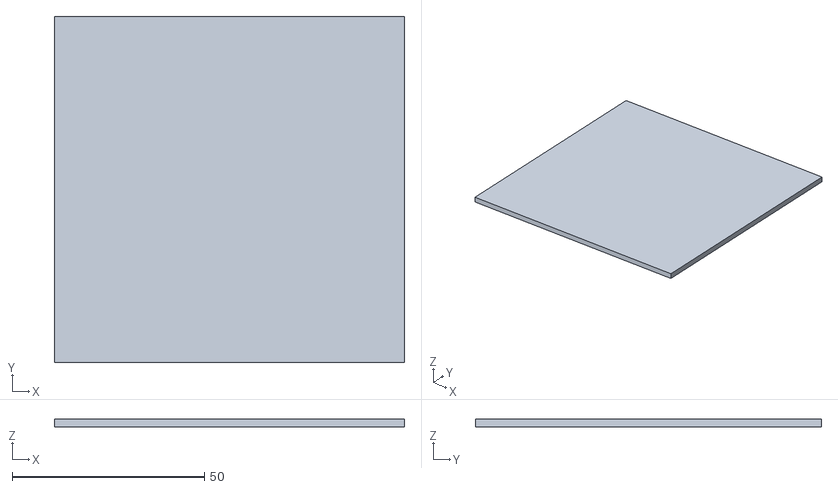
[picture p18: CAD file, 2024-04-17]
viko.stl
91.2 x 90.1 x 2.00

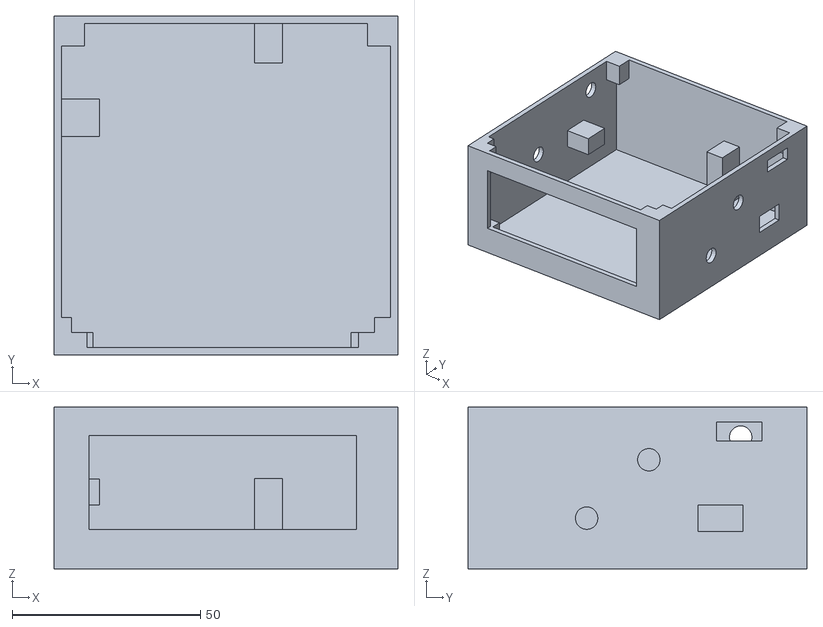
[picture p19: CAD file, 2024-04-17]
krabicka.stl
91.2 x 90.0 x 43.0

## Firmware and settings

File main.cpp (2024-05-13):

//Načtení všech potřebných knihoven
#include <WiFi.h>                   
#include <ESPAsyncWebServer.h>
#include <ArduinoOTA.h>             
#include <HTTPClient.h>             
#include <cbuf.h>
#include <SPI.h>
#include <Arduino.h>
#include <Preferences.h>
#include "web_content.h"
#include <LiquidCrystal_I2C.h>      
#include <IRremoteESP8266.h>
#include <IRrecv.h>
#include <BluetoothA2DPSink.h>
#include <Adafruit_VS1053.h>
#include <VS1053.h>                 
#include <RotaryEncoder.h>
#include <NTPClient.h>


//Definování pinů

//Zvuková karta VS1053b
#define VS1053_CS    5  
#define VS1053_DCS   16 
#define VS1053_DREQ  4  
#define VS1053_CSSD 17
#define CLK 18       
#define MISO 19      
#define MOSI 23  

//Infračervený přijímač (OUT)
#define IR_REC 2 

//Tlačítko pro přepínání mezi WiFi a Bluetooth režimy
#define BT_PIN 33 

//Rotační enkódér
#define BUTTON_PIN 12 
#define DT_PIN 13     
#define CLK_PIN 14    

//Název zařízení v Bluetooth režimu
#define BT_NAME "BT RECEIVER"

//Velikost bufferu (vyrovnávací paměti) pro knihovnu Adafruit_VS1053.h - režim Bluetooth
#define BUFFSIZE 32 

//Konstruktor pro SharedPrefs (ukládání výchozích proměnných při startu rádia)
Preferences preferences;

//Konstruktor pro zvukovou kartu a definice proměnných (knihovna Adafruit_VS1053.h, kterou jsem použil pro implementaci Bluetooth, na klasické VS1053.h se mi to nedařilo)
Adafruit_VS1053_FilePlayer bt_prehravac (VS1053_CS, VS1053_DCS, VS1053_DREQ, VS1053_CSSD);

//Konstruktor pro zvukovou kartu (knihovna VS1053.h, je mnou používaná jako výchozí knihovna pro internetový stream)
VS1053 stream_prehravac(VS1053_CS, VS1053_DCS, VS1053_DREQ); 

int lcd_adresa = 0x27; // Adresa LCD displeje (viz Tabulka 3.1 v dokumentu práce)

//Konstruktor pro LCD displej (16x2)
LiquidCrystal_I2C lcd(lcd_adresa, 16, 2); // Plošky A0, A1 a A2 ve výchozím stavu, proto zadám do proměnné lcd_adresa 0x27 

//Konstruktor pro rotační enkódér
RotaryEncoder *enkoder = nullptr;

//Testovací proměnné pro serial
bool IPdone = false;
String serverIP;

//Konstruktor pro webový server ESP v případě nepodaření připojení se k WiFi
AsyncWebServer server(80);


uint8_t buffer[2] = {0, 0};
int bufferID = 0;

//Definice režimů

//Módy enkódéru
enum enk_mod {
  enkoder_hlasitost,
  enkoder_stanice
};

//Módy přehrávání
enum rad_mod {
  BT_REZIM,
  WIFI_REZIM
};

//Módy rádia samotného
enum server_mod{
  RADIO,
  SERVER
};


//Výchozí hodnoty při startu rádia
//Jedná se o WiFi režim, nespouštět server a nastavení volby enkódérém na změnu hlasitosti
rad_mod rad_vych_mod = WIFI_REZIM;

server_mod server_vych_mod = RADIO;

enk_mod enk_vych_mod = enkoder_hlasitost;


//Zadání WiFi údajů
char ssid[] = "projekt";   
char pass[] = "projekt1"; 

WiFiUDP ntpUDP;
NTPClient timeClient(ntpUDP);

//Vstupní údaje pro přístup k serveru (jakmile se spustí - objeví se jeho IP na displeji spolu s nápisem SERVER REZIM)
char server_ssid[] = "Internet Radio Player";
char server_heslo[] = "player123";

//Definice pole mp3buff o velikosti BUFFSIZE 
uint8_t mp3buff[BUFFSIZE];

//Definice pole hlavičky pro Bluetooth (nutné, bez tohoto naplnění by komunikace nebyla možná)
unsigned char bt_wav_header[44] = {
    0x52, 0x49, 0x46, 0x46, 
    0xFF, 0xFF, 0xFF, 0xFF, 
    0x57, 0x41, 0x56, 0x45, 
    0x66, 0x6d, 0x74, 0x20, 
    0x10, 0x00, 0x00, 0x00, 
    0x01, 0x00,             
    0x02, 0x00,             
    0x44, 0xac, 0x00, 0x00, 
    0x10, 0xb1, 0x02, 0x00, 
    0x04, 0x00,             
    0x10, 0x00,             
    0x64, 0x61, 0x74, 0x61, 
    0xFF, 0xFF, 0xFF, 0xFF  
};

//Konstruktor pro Bluetooth komunikaci
BluetoothA2DPSink a2dp_sink;

//Definice proměnné pro informace o Bluetooth zasílané připojeným zdrojem audia (např. interpret)
char bluetooth_media_title[255];
//Definice boolu pro dotaz na doručená data 
bool f_bluetoothsink_metadata_received = false;
//Konstruktor pro circular buffer (cirkulární vyrovnávací paměť - FIFO (First In - First Out))
cbuf circBuffer(1024 * 24);

//Definice hosta (serveru),cesty za streamem, o který se žádá a portu
const char *host;                                                                                                                                                                                                                                                                                   // Zde se uloží adresa serveru s požadovaným streamem
const char *cesta;          


//Definice proměnných pro stanice
int ID_stanice=1;        //Číslo aktuálně přehráváné stanice, je výchozí po resetu hodnot
int pamet_ID_stanice;    //Paměť poslední přehráváné stanice
String nazev="";         //Název aktuálně přehrávané stanice
String nazevCely="";
String nar="";


//Definice proměnných LCD displeje
int x1 = 16;   //Počet řádků displeje
int x2 = 0;    //Kde se nachází počáteční znak
int delkaTextu = 0;    //Výchozí délka textu
String odsazeni = "                "; //Odsazení pro scrolling displeje

int Obnova;              //Obnova určuje, jak často se má displej obnovovat, kdyby se obnovoval s rychlostí taktu, s jakým pracuje MCU, zobrazily by se artefakty
int Volume = 80;           //Výhozí hlasitost při zapnutí v rádio režimu, je výchozí po resetu hodnot
int VolumeBT = 40;         //Výhozí hlasitost při zapnutí v Bluetooth režimu, je výchozí po resetu hodnot
int VolumeBTKontrola;      //Porovnání hodnot Bluetooth hlasitosti s předchozí pro aktualizaci
int predVolume = Volume;   //Porovnání hodnot hlasitosti v rádio režimu
int zalohaVolume;          //Slouží k uložení proměnné pro hlasitost výstupu v rádio režimu
int zalohaVolumeBT;        //Slouží k uložení proměnné pro hlasitost výstupu v Bluetooth režimu
int zaloha_stanice;        //Slouží k uložení proměnné pro ID stanice

//Definice počtu stanic (potřebná pro nastavení intervalů možností otáčení enkódérem nebo přepínání pomocí ovladače)
int pocet_stanic = 30;     //Potřebné upravit!!! Shodné s počtem case ve WIFI_REZIM   

bool toggle = true; //Proměnná pro mute v rádio režimu
bool toggleBT = true; //Proměnná pro přepnutí ovladačem v rádio i bluetooth režimu
bool toggleBTVol = true; //Proměnná pro mute v bluetooth režimu

//Definice ostatních proměnných
volatile int enkoderPozST = ID_stanice;
volatile int enkoderPozVO = Volume;

int buttonState = HIGH;        
int lastButtonState = HIGH;    
int BTbuttonState = HIGH; 

//Detekce nechtěného přepínání mezi rádio a BT režimem
unsigned long BTlastButtonPressTime = 0;
unsigned long BTdebounceDelay = 2000;
bool buttonPressed = false;

//Konstruktor pro webclienta (nutné pro načítání streamů ze serveru)
WiFiClient webclient;

//Konstruktory pro infračervenou diodu
IRrecv irrecv(IR_REC);
decode_results decod_prij;



String Scroll_displeje(String LCD_text){
  String LCD_hot;
  String LCD_proces = odsazeni + LCD_text + odsazeni;
  LCD_hot = LCD_proces.substring(x1,x2);
  x1++;
  x2++;
  if (x1>LCD_proces.length()){
    x1=16;
    x2=0;
  }
  return LCD_hot;
}  


//Funkce pro spouštění serveru v případě, že se ESP32 nedokázalo připojit k žádné WiFi
void serverRun() {
    WiFi.softAP(server_ssid, server_heslo);

    server.on("/", HTTP_GET, [](AsyncWebServerRequest *request){
        request->send(200, "text/html", obsahWeb); //Vytvoří se server na IP zobrazené na displeji, kde se zobrazí html kód z proměnné obsahWeb, která je uložená ve flash spolu s programem
    });
    server.on("/", HTTP_POST, [](AsyncWebServerRequest *request){
        if(request->hasParam("ssid", true) && request->hasParam("password", true)) {
            AsyncWebParameter* ssidParam = request->getParam("ssid", true);
            AsyncWebParameter* passwordParam = request->getParam("password", true);

            String newSSID = ssidParam->value();
            String newPassword = passwordParam->value();
            //Ukládání zadaného SSID a hesla do sharedPrefs inicializované při spuštění ESP
            preferences.begin("wifi", false);
            preferences.putString("ssid", newSSID);
            preferences.putString("password", newPassword);
            preferences.end();
            delay(1000);
            ESP.restart();
        } else {
            request->send(400, "text/plain", "Chybí potřebné parametry");
        }
    });
    server.begin();
    //Serial.println("Server běží!");
}


//Testovací případ pro reset hodnot do původního stavu
void resetHodnot(){
  preferences.begin("radio", false);
      preferences.putInt("Volume", 80);
      preferences.putInt("VolumeBT", 40);
      preferences.putInt("ID_stanice", 1);
      preferences.end();
  preferences.begin("wifi", false);
            preferences.putString("ssid", "My tady");
            preferences.putString("password", "ST59RE65KR97PA01");
            preferences.end();
  
}

//Testovací případ pro reset hodnot s testovaným špatně zadaným SSID
void resetTest(){
   preferences.begin("wifi", false);
            preferences.putString("ssid", "d");
            preferences.putString("password", "d");
            preferences.end();
}


//Metadata z připojeného zařízení skrze Bluetooth (interpret, atd.) - využívám jen vypisování do Serialu
void metadata(uint8_t data1, const uint8_t *data2) {
    Serial.printf("Metadata: ID: 0x%x, %s\n", data1, data2);
    if (data1 == 0x1) { 
        strncpy(bluetooth_media_title, (char *)data2, sizeof(bluetooth_media_title) - 1);
    } else if (data1 == 0x2) {
        strncat(bluetooth_media_title, " - ", sizeof(bluetooth_media_title) - 1);
        strncat(bluetooth_media_title, (char *)data2, sizeof(bluetooth_media_title) - 1);
        f_bluetoothsink_metadata_received = true;
    }
   }

//Průběh Bluetooth streamu, volá se ve smyčce
void handle_stream() {
  if (circBuffer.available()) { 
    if (bt_prehravac.readyForData()) { //Dotaz na zvukovou kartu, zda může přijímat další data
      int bytesRead = circBuffer.read((char *)mp3buff, BUFFSIZE); 
      //Zachycení chybného čtení dat
      if (bytesRead != BUFFSIZE) Serial.printf("Málo dat v bufferu, kvalita audia může být ovlivněna", bytesRead);
      bt_prehravac.playData(mp3buff, bytesRead); //Zaslání dat do zvukové karty
    }
  }
}

//Naplnění bufferu
void dat_stream(const uint8_t *data, uint32_t length) {
  if (circBuffer.room() > length) { 
    if (length > 0) { 
      circBuffer.write((char *)data, length);       
    }
  } else {
    Serial.println("\nŽádná streamovací data!");
  }  
}



//Funkce volána při přepnutí z WiFi režimu do Bluetooth režimu
void startBluetooth(){
Serial.println("Přepínám na BT režim");
 if (rad_vych_mod != BT_REZIM){
    lcd.clear();
 lcd.setCursor(0, 0);
 lcd.print("BLUETOOTH");
 lcd.setCursor(0,1); 
 lcd.print("Nastavovani..."); //Vypsání BLUETOOTH na displej
  }
 
stream_prehravac.stopSong(); //Pozastavení inicializované knihovny VS1053.h
stream_prehravac.softReset();
delay(1000);
if (!bt_prehravac.begin()) {
     Serial.println(F("Chyba VS1053b, zkontroluj zapojení pinů!"));
     lcd.clear();
     lcd.setCursor(0,0);
     lcd.print("Chyba E1");
     while(1);
  } 
bt_prehravac.begin(); //Start zvukové karty pomocí knihovny Adafruit_VS1053.h

  
  ArduinoOTA.end(); //Vypnutí OTA 
  WiFi.mode(WIFI_OFF); //Vypnutí WiFi
  WiFi.disconnect();
  Serial.println("WiFi režim: " + WiFi.getMode()); //Testovací výpis pro kontrolu
  delay(1000);
  circBuffer.flush(); //Vyprázdnění vyrovnávací paměti
  Serial.println(stream_prehravac.isChipConnected()); //Testovací výpis pro kontrolu
  a2dp_sink.set_stream_reader(dat_stream, false); //Nastavení Bluetooth streamu
  a2dp_sink.set_avrc_metadata_callback(metadata); //Nastavení metadat - nepoužívám jej pro výpis jinde, než v konzoli, není třeba
  a2dp_sink.start(BT_NAME); //Start Bluetooth se jménem v BT_NAME
  Serial.println(a2dp_sink.get_connected_source_name()); //Testovací výpis pro kontrolu
  delay(1000);
  circBuffer.write((char *)bt_wav_header, 44);
  delay(1000);

  Serial.println("Bluetooth režim"); //Testovací výpis pro kontrolu

  if (rad_vych_mod != BT_REZIM){ //Výpis informace o režimu na LCD displej spolu s názvem BT
    lcd.clear();
 lcd.setCursor(0, 0);
 lcd.print("BLUETOOTH");
 lcd.setCursor(0,1); 
 lcd.print(BT_NAME);
  }
  
  rad_vych_mod = BT_REZIM; //Přepnutí režimu na BT_REZIM
}

//Tato funkce je volána při přepínání z Bluetooth do rádiového režimu
void stopBluetooth(){
   lcd.clear(); //Výpis toho, co se s rádiem děje
 lcd.setCursor(0, 0);
 lcd.print("BLUETOOTH");
 lcd.setCursor(0,1); 
 lcd.print("Vypinani...");
 a2dp_sink.end();
 delay(500);

   Serial.println("Přepínám na WiFi režim");
   bt_prehravac.stopPlaying();
   bt_prehravac.reset();
   ESP.restart();
   /*delay(2000);

  stream_prehravac.begin();
  stream_prehravac.setVolume(Volume);
  Serial.println(stream_prehravac.isChipConnected());
  delay(10000);


  //WiFi.mode(WIFI_STA);         // Mód WiFi
  //delay(10000);
  WiFi.begin(ssid, pass);
   Serial.println("WiFi režim: " + WiFi.getMode());
  delay(10000);
 Serial.println("WiFi režim");
//  ArduinoOTA.setHostname("ESP32");
//  ArduinoOTA.begin();
//   delay(5000);
//   Serial.println("OTA aktivní");
  
  rad_vych_mod = WIFI_REZIM; // Set the mode to WIFI_REZIM
*/
}


void getPoz()
{
  enkoder->tick(); //Zjištění stavu enkóderu
}
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
void loop()
{  

switch(server_vych_mod){//Přepínání mezi RADIO a SERVER režimem
  case RADIO:

switch(rad_vych_mod)//Přepínání mezi WiFi a Bluetooth režimem

{
case WIFI_REZIM:

if (Obnova >= 450){//Po kolika cyklech se má obnovit LCD

  Obnova = 0; //Reset

  timeClient.update();
  lcd.setCursor(5, 1);
  String formCas = timeClient.getFormattedTime();
  formCas.remove(5);
  lcd.print(formCas);
  
  String nazevCely =  nazev + "|" + nar;
  lcd.setCursor(0, 0);
  String pohybText = Scroll_displeje(nazevCely);
  lcd.print(pohybText); //vypsání infa o stanici na první řádek LCD
  lcd.setCursor(0,1);
  lcd.print(ID_stanice);
  
  int mapVolume = map(Volume, 30, 100, 1, 100); //Namapování hodnot u WiFi hlasitosti
              
 if (Volume != predVolume) {
                lcd.setCursor(12, 1);
                lcd.print("   "); //Smazání druhého řádku LCD displeje
                lcd.setCursor(12, 1);
                if (Volume < 30){
                  lcd.print("VYP");//vypsání na druhý řádek LCD
                }
                else{
                lcd.print(mapVolume);//vypsání na druhý řádek LCD
                lcd.print ("%");
                }
                //aktualizace hlasitosti
                predVolume = Volume;
            }

            else{
              lcd.setCursor(12, 1);
              if (Volume < 30){
                  lcd.print("VYP"); //vypsání na druhý řádek LCD
                }
                else{
                lcd.print(mapVolume);//vypsání na druhý řádek LCD
                lcd.print ("%");
                }
            }

preferences.begin("radio", false); //ukládání do prefs
preferences.putInt("Volume", Volume);
preferences.putInt("ID_stanice", ID_stanice);
preferences.end();
}



if (!WiFi.isConnected()){ //V případě odpojení od WiFi
  Serial.println(WiFi.getMode());
  WiFi.mode(WIFI_STA);
  delay(1000);
   Serial.println(WiFi.getMode());
  WiFi.begin(ssid, pass);
  delay(10000);
  Serial.println(WiFi.localIP());

  // if (WiFi.isConnected()){
  //   ArduinoOTA.setHostname("ESP32");
  //   ArduinoOTA.begin();
  //   Serial.println("OTA aktivní");
  // }
}

ArduinoOTA.handle(); //Funkce OTA aktivní
Obnova=Obnova+1; //Přičtení obnovy LCD

stream_prehravac.setVolume(Volume);  
 switch(ID_stanice){              // Přepínání stanic - ID stanice
        case 1:
        
             nazev = "Hitradio Orion";       
             host = "ice.abradio.cz";         
             cesta= "/orion128.mp3";
             nar ="CZ";
            break;
        case 2:
        
           nazev = "Evropa 2"; 
           host= "25433.live.streamtheworld.com";          
           cesta= "/EVROPA2.mp3";
           nar ="CZ";
           break;


        case 3:
        
           nazev = "Radio Blanik"; 
           host= "ice.abradio.cz";          
           cesta= "/blanikfm128.mp3";
           nar ="CZ";
           break;

        case 4:
          nazev = "Radio Kiss"; 
           host= "icecast4.play.cz";          
           cesta= "/kiss128.mp3";
           nar ="CZ";
           break;


        case 5:
          nazev = "Hitradio 90"; 
           host= "ice.abradio.cz";          
           cesta= "/hit90128.mp3";
           nar ="CZ";
  break;

  case 6:
          nazev = "Radio Cas"; 
           host= "icecast6.play.cz";          
           cesta= "/casradio128.mp3";
            nar ="CZ";
  break;

  case 7:
          nazev = "Country Radio"; 
           host= "icecast4.play.cz";          
           cesta= "/country128.mp3";
           nar ="CZ";
  break;

  case 8:
          nazev = "Frekvence 1"; 
           host= "ice.actve.net";          
           cesta= "/fm-frekvence1-128";
          nar ="CZ";
  break;
  
  case 9:
          nazev = "Radio Impuls"; 
           host= "icecast1.play.cz";          
           cesta= "/impuls128.mp3"; 
           nar ="CZ";
  break;
  case 10:
          nazev = "Fajn Radio"; 
           host= "ice.abradio.cz";          
           cesta= "/fajn128.mp3";
           nar ="CZ";
  break;
  case 11:
          nazev = "Rock Radio"; 
           host= "ice.abradio.cz";          
           cesta= "/rockradio128.mp3";
           nar ="CZ";
  break;

  case 12:
          nazev = "Radio Beat"; 
           host= "ice5.abradio.cz";          
           cesta= "/beat128.mp3";
nar ="CZ";
  break;

  case 13:
          nazev = "Hey Radio"; 
           host= "icecast3.play.cz";          
           cesta= "/hey-radio128.mp3";
nar ="CZ";
  break;

  case 14:
          nazev = "Hitradio FM Plus"; 
           host= "ice.abradio.cz";          
           cesta= "/fmplus128.mp3";
nar ="CZ";
  break;

  case 15:
          nazev = "Signal Radio"; 
           host= "icecast1.play.cz";          
           cesta= "/signal192.mp3";
  break;
nar ="CZ";
  case 16:
          nazev = "SRo 1 Radio Slovensko";
           host= "icecast.stv.livebox.sk";          
           cesta= "/slovensko_128.mp3";
nar ="SK";
  break;

  case 17:
          nazev = "Radio Devin (SRo 3)"; 
           host= "icecast.stv.livebox.sk";          
           cesta= "/devin_128.mp3";
nar ="SK";
  break;
  case 18:
          nazev = "Europa 2"; 
           host= "stream.bauermedia.sk";          
           cesta= "/europa2.mp3";
nar ="SK";
  break;
  case 19:
          nazev = "Radio Jemne"; 
           host= "stream.bauermedia.sk";          
           cesta= "/melody-hi.mp3";
nar ="SK";
  break;
  case 20:
          nazev = "Radio Pyramida"; 
           host= "icecast.stv.livebox.sk";          
           cesta= "/klasika_128.mp3";
nar ="SK";
  break;

  case 21:
          nazev = "Radio Tok FM"; 
           host= "radiostream.pl";          
           cesta= "/tuba10-1.mp3";
nar ="PL";

  break;

  case 22:
          nazev = "Radio Zlote Przeboje"; 
           host= "radiostream.pl";          
           cesta= "/tuba8936-1.mp3";
nar ="PL";

  break;

  case 23:
          nazev = "Nova FM"; 
           host= "live-bauerdk.sharp-stream.com";          
           cesta= "/nova128.mp3";
nar ="DK";
  break;
  case 24:
          nazev = "VLR"; 
           host= "webradio.vlr.dk";          
           cesta= "/vlrvejle";
nar ="DK";
  break;

case 25:
          nazev = "Hit Radio FFH"; 
           host= "mp3.ffh.de";          
           cesta= "/radioffh/hqlivestream-osthessen.mp3";
nar ="DE";
  break;
  case 26:
          nazev = "BB Radio"; 
           host= "irmedia.streamabc.net";          
           cesta= "/irm-bbradiolive-mp3-128-4531502";
nar ="DE";
  break;
  case 27:
          nazev = "Rock FM"; 
           host= "flucast-b02-06.flumotion.com";          
           cesta= "/cope/rockfm.mp3";
nar ="ES";
  break;
  case 28:
          nazev = "Euskadi Irratia"; 
           host= "mp3-eitb.stream.flumotion.com";          
           cesta= "/eitb/euskadiirratia.mp3"; 
nar ="ES";
  break;
  case 29:
          nazev = "Russkoe Radio"; 
           host= "rusradio.hostingradio.ru";          
           cesta= "/rusradio128-f.mp3";
nar ="RU";
  break;
  case 30:
          nazev = "Sverige Radio P1"; 
           host= "http-live.sr.se";          
           cesta= "/p1-mp3-192";
nar ="SE";
  break;
     }
            

    
  stream(); //funkce pro stream

  IROvladac(); //aktualizace IR

  Enkoder();//aktualizace enkódéru

  handleButton(); //aktualizace tlačítka
  
  Prikazy();//aktualizace příkázů
  
 BTbutton();//aktualizace BT tlačítka

 break;

//Funkce v BT režimu
case BT_REZIM:
 //Pokud není BT spuštěno, zapni jej
if (!a2dp_sink.is_connected()){
   startBluetooth();
}

//Refresh LCD v BT režimu
if (Obnova >= 20000){
       Obnova=0;
  bt_prehravac.setVolume(VolumeBT, VolumeBT); //Nastavení hlasitosti VS1053b

if (VolumeBT != VolumeBTKontrola){//Obnovení displeje v případě, že se změní hodnota hlasitosti
  VolumeBTKontrola = VolumeBT;
//Mapování hodnot hlasitosti v jiném pořadí a v jiném intervalu
int mapVolumeBT = map(VolumeBT, 1, 100, 100, 1);
if (mapVolumeBT == 0 || VolumeBT == 254){
    lcd.clear();
  lcd.setCursor(0, 0);
 lcd.print("BLUETOOTH REZIM");//Výpis na LCD displej
 lcd.setCursor(12,1); 
    lcd.print("VYP"); //Výpis na LCD displej            
}
else {
  lcd.clear();
 lcd.setCursor(0, 0);
 lcd.print("BLUETOOTH REZIM");//Výpis na LCD displej
 lcd.setCursor(12,1); 
 lcd.print (mapVolumeBT);
 lcd.print ("%");
}}
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
